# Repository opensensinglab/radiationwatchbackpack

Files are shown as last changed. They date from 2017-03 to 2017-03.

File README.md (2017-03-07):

External signal analysis backpack for the Radiation Watch Type 5 high-energy particle detector
======

Work-in-progress.  Please use at your own risk. <br>

This is a board intended to function as an external comparator for the Radiation Watch Type 5 high energy particle detector.  The stock RWT5 comes with a comparator whose threshold appears very conservative, and it appears that lower-energy particles can be detected by affixing an external comparator such as this.  This project is also working towards including an energy-level detection mechanism. <br>

Earlier versions of this backpack were used for the Open Source Desktop Computed Tomography Scanner (OpenCT, http://www.tricorderproject.org/blog/tag/openct/), and the Arducoder Mini open-source science tricorder-like device ( https://hackaday.io/project/1395-open-source-science-tricorder ). 

# Open Source

This project is open source software and hardware, and is released under various open licenses.

# Disclaimer

**DISCLAIMER OF WARRANTIES AND LIMITATION OF LIABILITY.**

UNLESS OTHERWISE SEPARATELY UNDERTAKEN BY THE LICENSOR, TO THE EXTENT POSSIBLE, THE LICENSOR OFFERS THE LICENSED MATERIAL AS-IS AND AS-AVAILABLE, AND MAKES NO REPRESENTATIONS OR WARRANTIES OF ANY KIND CONCERNING THE LICENSED MATERIAL, WHETHER EXPRESS, IMPLIED, STATUTORY, OR OTHER. THIS INCLUDES, WITHOUT LIMITATION, WARRANTIES OF TITLE, MERCHANTABILITY, FITNESS FOR A PARTICULAR PURPOSE, NON-INFRINGEMENT, ABSENCE OF LATENT OR OTHER DEFECTS, ACCURACY, OR THE PRESENCE OR ABSENCE OF ERRORS, WHETHER OR NOT KNOWN OR DISCOVERABLE. WHERE DISCLAIMERS OF WARRANTIES ARE NOT ALLOWED IN FULL OR IN PART, THIS DISCLAIMER MAY NOT APPLY TO YOU.

TO THE EXTENT POSSIBLE, IN NO EVENT WILL THE LICENSOR BE LIABLE TO YOU ON ANY LEGAL THEORY (INCLUDING, WITHOUT LIMITATION, NEGLIGENCE) OR OTHERWISE FOR ANY DIRECT, SPECIAL, INDIRECT, INCIDENTAL, CONSEQUENTIAL, PUNITIVE, EXEMPLARY, OR OTHER LOSSES, COSTS, EXPENSES, OR DAMAGES ARISING OUT OF THIS PUBLIC LICENSE OR USE OF THE LICENSED MATERIAL, EVEN IF THE LICENSOR HAS BEEN ADVISED OF THE POSSIBILITY OF SUCH LOSSES, COSTS, EXPENSES, OR DAMAGES. WHERE A LIMITATION OF LIABILITY IS NOT ALLOWED IN FULL OR IN PART, THIS LIMITATION MAY NOT APPLY TO YOU.

THE DISCLAIMER OF WARRANTIES AND LIMITATION OF LIABILITY PROVIDED ABOVE SHALL BE INTERPRETED IN A MANNER THAT, TO THE EXTENT POSSIBLE, MOST CLOSELY APPROXIMATES AN ABSOLUTE DISCLAIMER AND WAIVER OF ALL LIABILITY.

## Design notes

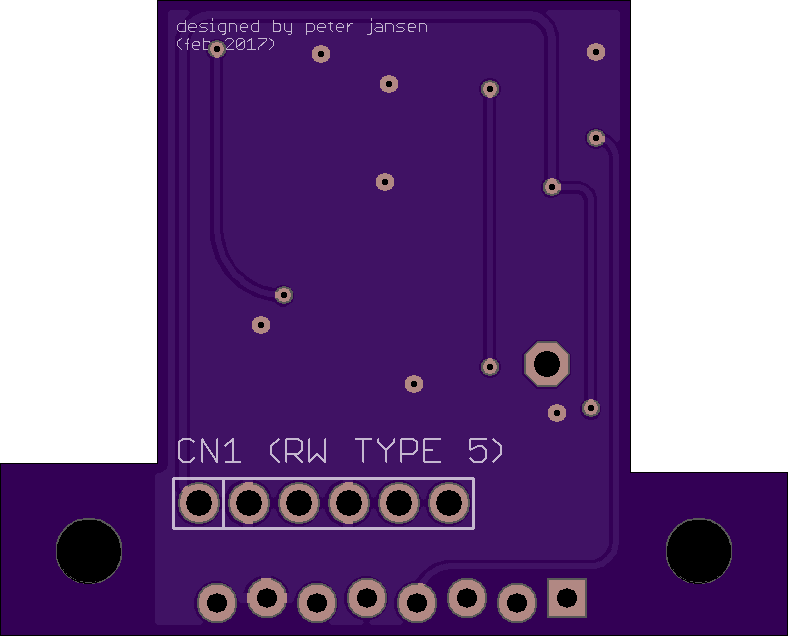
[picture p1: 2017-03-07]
hardware/version1/backpack_back.png

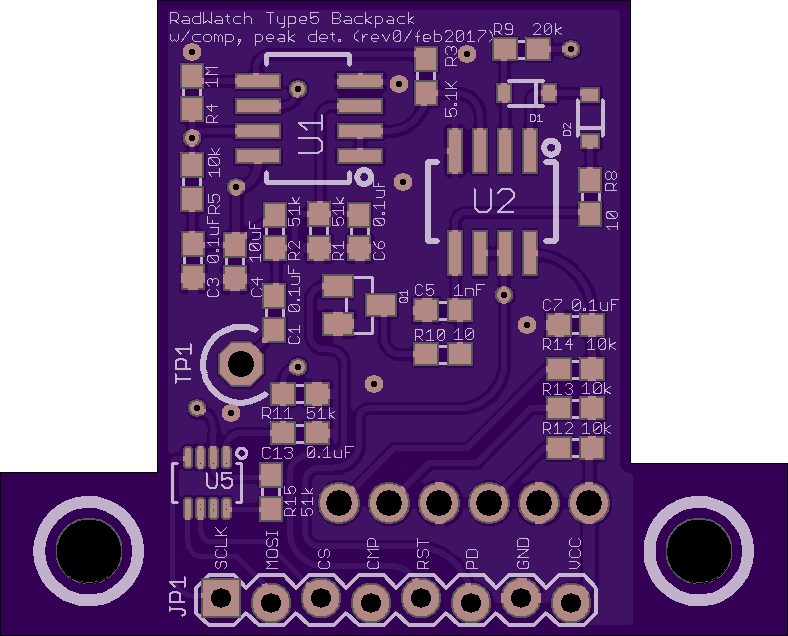
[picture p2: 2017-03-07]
hardware/version1/backpack_front.png

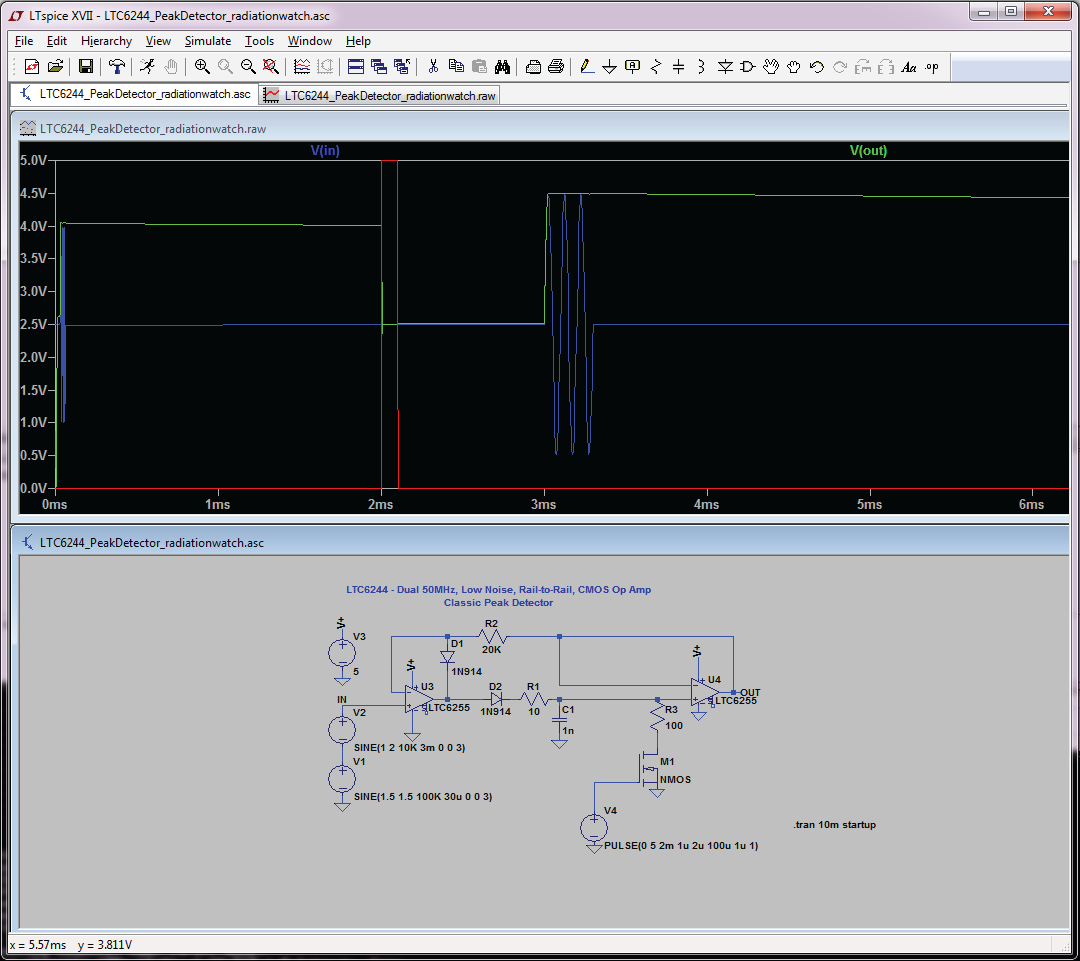
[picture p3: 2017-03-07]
hardware/version1/ltspice_simulation.png

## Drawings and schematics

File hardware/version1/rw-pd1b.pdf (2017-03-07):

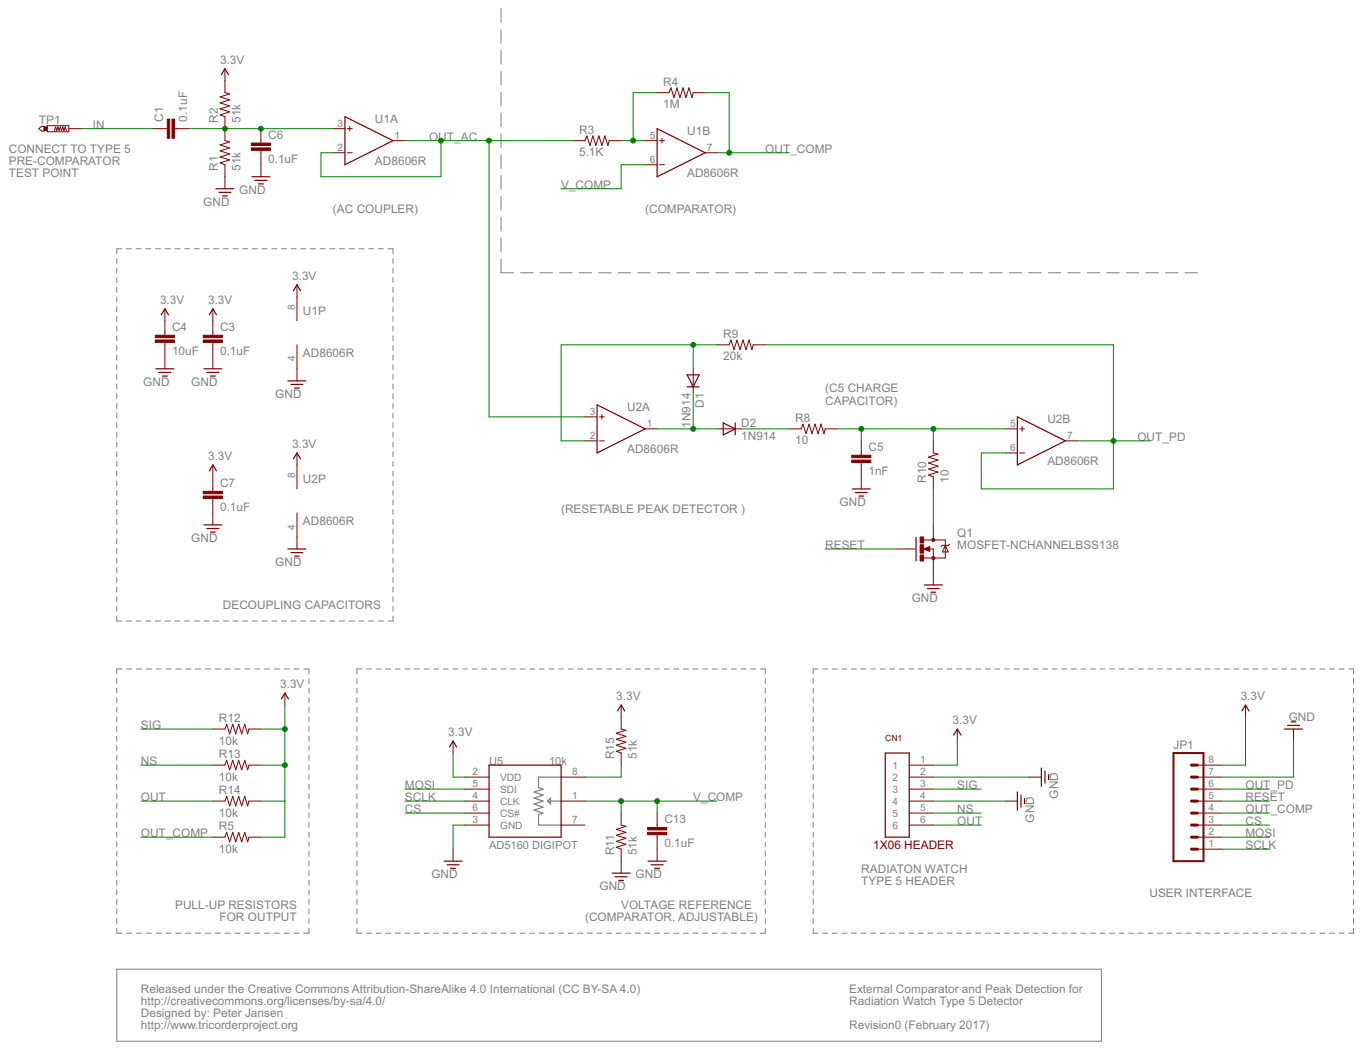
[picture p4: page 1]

Released under the Creative Commons Attribution-ShareAlike 4.0 International (CC BY-SA 4.0)
http://creativecommons.org/licenses/by-sa/4.0/
Designed by: Peter Jansen

External Comparator and Peak Detection for Radiation Watch Type 5 Detector

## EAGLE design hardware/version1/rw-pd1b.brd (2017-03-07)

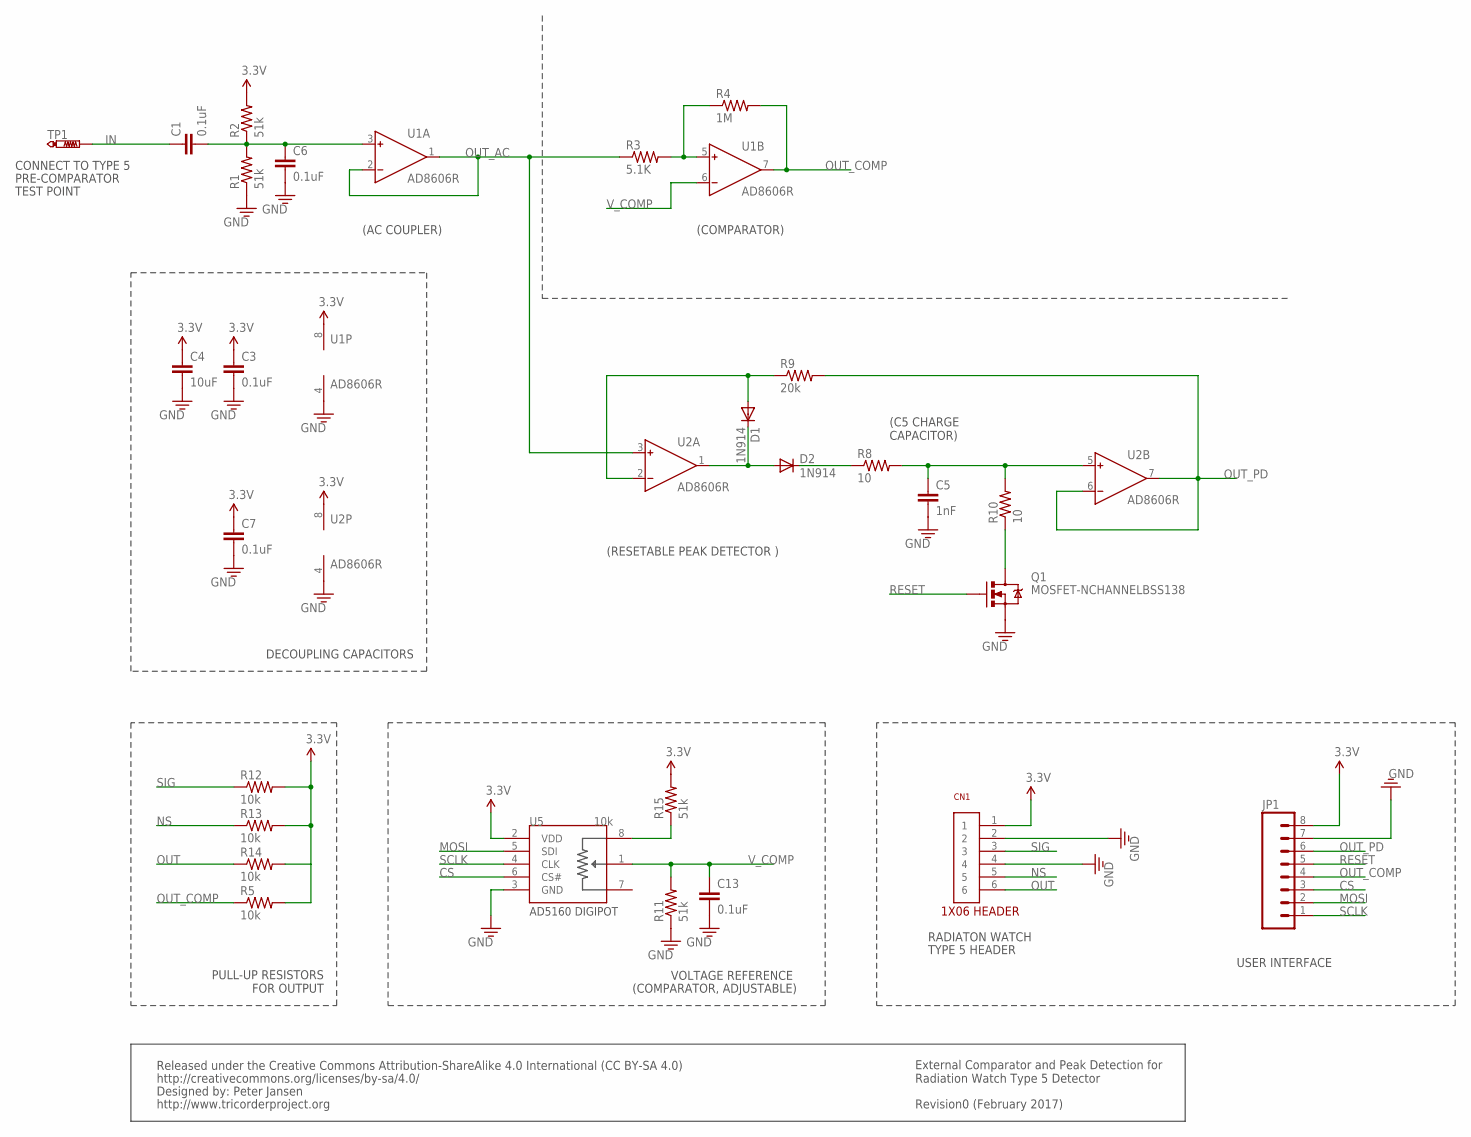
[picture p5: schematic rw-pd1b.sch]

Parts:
C1, C3, C6, C7, C13: 0.1uF; 0603
C4: 10uF; 0603
C5: 1nF; 0603
CN1: 1X06
D1, D2: 1N914; SOD-323
JP1: M08LOCK; 1X08_LOCK
Q1: MOSFET-NCHANNELBSS138; SOT23
R1, R2, R11, R15: 51k; 0603
R3: 5.1K; 0603
R4: 1M; 0603
R5, R12, R13, R14: 10k; 0603
R8, R10: 10; 0603
R9: 20k; 0603
TP1: PTR1PAD1-13; P1-13
U1, U2: AD8606R; SO8
U5: 10k; SOT-23-8

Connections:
3.3V: C3.1, C4.1, C7.1, CN1.1, JP1.8, R2.2, R5.2, R12.2, R13.2, R14.2, R15.2, U1.8 (V+), U2.8 (V+), U5.2 (VDD)
CS: JP1.3, U5.6 (CS#)
GND: C3.2, C4.2, C5.2, C6.2, C7.2, C13.2, CN1.2, CN1.4, JP1.7, Q1.2 (S), R1.1, R11.1, U1.4 (V-), U2.4 (V-), U5.3 (GND)
IN: C1.1, TP1.TP
MOSI: JP1.2, U5.5 (SDI)
unnamed: C1.2, C6.1, R1.2, R2.1, U1.3 (IN+)
unnamed: R3.2, R4.1, U1.5 (IN+)
unnamed: D1.A, R9.1, U2.2 (IN-)
unnamed: D1.C, D2.A, U2.1 (OUT)
unnamed: D2.C, R8.1
unnamed: C5.1, R8.2, R10.2, U2.5 (IN+)
unnamed: Q1.3 (D), R10.1
unnamed: R15.1, U5.8 (A)
NS: CN1.5, R13.1
OUT: CN1.6, R14.1
OUT_AC: R3.1, U1.1 (OUT), U1.2 (IN-), U2.3 (IN+)
OUT_COMP: JP1.4, R4.2, R5.1, U1.7 (OUT)
OUT_PD: JP1.6, R9.2, U2.6 (IN-), U2.7 (OUT)
RESET: JP1.5, Q1.1 (G)
SCLK: JP1.1, U5.4 (CLK)
SIG: CN1.3, R12.1
V_COMP: C13.1, R11.2, U1.6 (IN-), U5.1 (W)

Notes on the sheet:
(AC COUPLER)
(COMPARATOR)
CONNECT TO TYPE 5
PRE-COMPARATOR
TEST POINT
RADIATON WATCH
TYPE 5 HEADER
Released under the Creative Commons Attribution-ShareAlike 4.0 International (CC BY-SA 4.0)
http://creativecommons.org/licenses/by-sa/4.0/
Designed by: Peter Jansen
http://www.tricorderproject.org
Revision0 (February 2017)
External Comparator and Peak Detection for Radiation Watch Type 5 Detector
(C5 CHARGE CAPACITOR)
(RESETABLE PEAK DETECTOR )
VOLTAGE REFERENCE
(COMPARATOR, ADJUSTABLE)
PULL-UP RESISTORS FOR OUTPUT
DECOUPLING CAPACITORS
USER INTERFACE

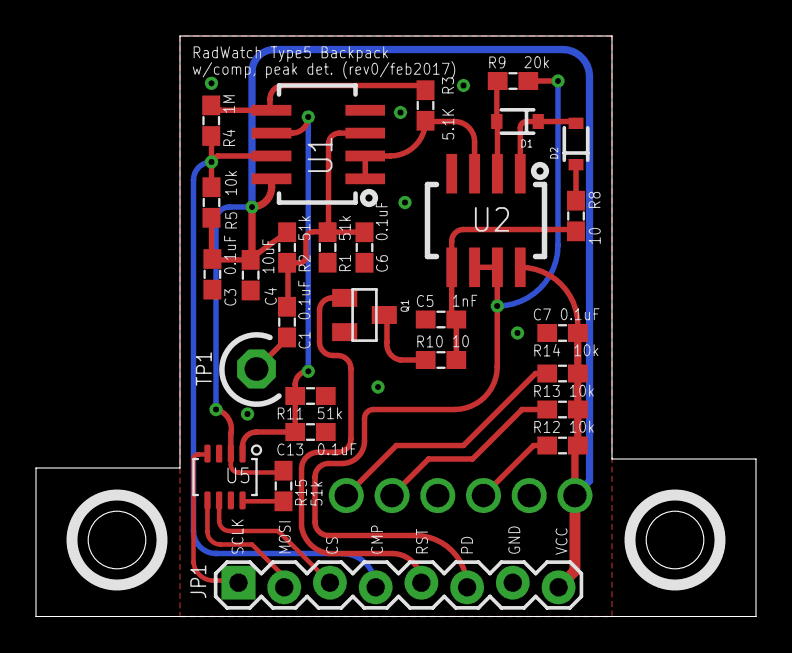
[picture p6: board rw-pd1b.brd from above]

Board: 2 copper layers, 40.0 x 32.2 mm, 29 parts (1 on the bottom side), 22 nets.

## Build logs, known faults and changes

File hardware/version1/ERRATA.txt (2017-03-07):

March 5/2017: Only partially tested.  Peak detector appears to be working okay, but holds for a little less time than expected (but still long enough to be read by triggering an interrupt using the external comparator to read the peak detector output with an Arduino ADC).  R15 on the reference voltage divider should be lower than 51k -- replaced with 43.3k, and works okay.

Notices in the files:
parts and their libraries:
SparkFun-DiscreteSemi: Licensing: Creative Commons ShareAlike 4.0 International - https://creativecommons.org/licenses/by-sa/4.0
